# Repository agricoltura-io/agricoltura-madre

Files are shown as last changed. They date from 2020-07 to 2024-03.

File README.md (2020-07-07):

# agricoltura-madre
Wired and Wireless gateway for all Agricoltura sensors/module supports RS485, Sub1GHZ, and 2.4GHZ networks

Quick Specs:

Beaglebone Green Based Version - Cape
- Seeedstudio Beaglebone Green
- 2x RS485 ports
- Sub 1GHZ wirless modem with SMA Antenna Connector
- 2.4GHZ wireless modem with SMA Antenna connector, supporting all 2.4G types
- WiFi modem with SMA antenna connector
- 1x USB 2.0 ports
- USB serial monitor connection
- Ethernet

Beaglebone SiP Based Version
- OSD335x Family System-in-package, running Debian Linux
- 4x RS485 ports
- Sub 1GHZ wirless modem with SMA Antenna Connector
- 2.4GHZ wireless model with SMA Antenna connector, supporting all 2.4G types
- WiFi modem with SMA antenna connector
- 2X USB 2.0 ports
- USB serial monitor connection
- Ethernet

Raspberry Pi 4 based version:
- 2x RS485 ports
- Sub 1GHZ wirless modem with SMA Antenna Connector
- 2.4GHZ wireless model with SMA Antenna connector, supporting all 2.4G types
- Integrated WiFi (RPi4)
- USB ports (RPi4)
- Ethernet
- PoE or 24VAC Power

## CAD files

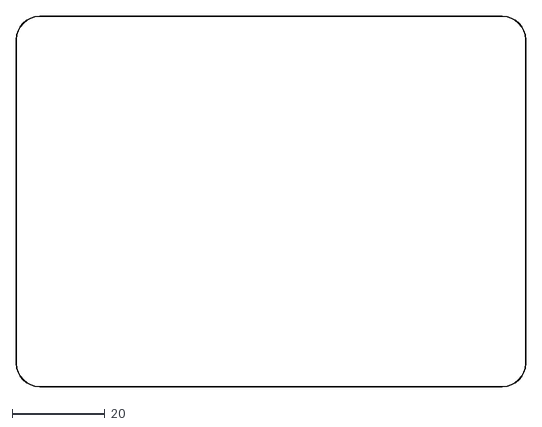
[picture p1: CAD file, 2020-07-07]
PCB/Cape/agricoltura-madre-cape-B/Vine_Ivy_BRD_Shape.dxf
110.0 x 80.0

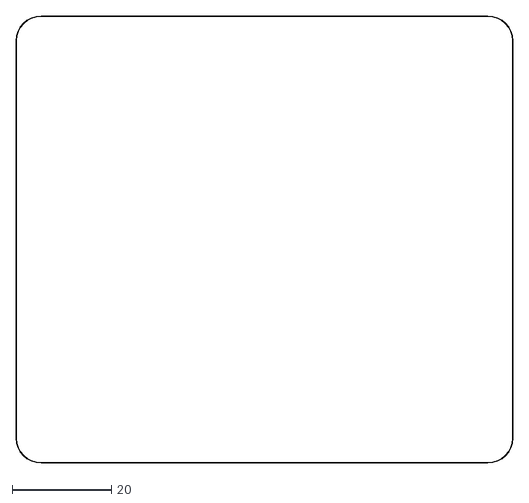
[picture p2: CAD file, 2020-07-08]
PCB/Cape/agricoltura-madre-cape/madre_BRD_Shape.dxf
100.0 x 90.0

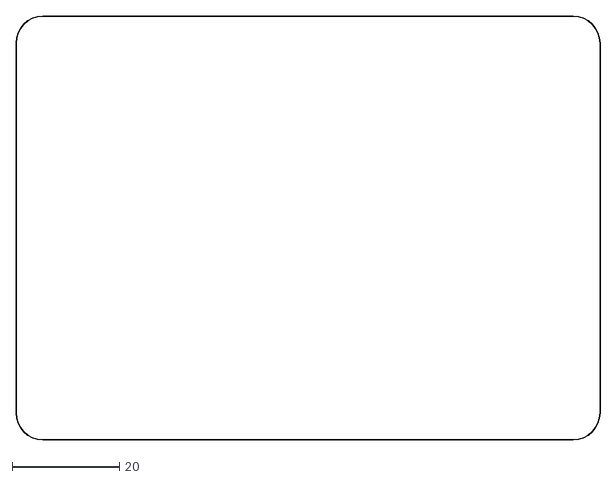
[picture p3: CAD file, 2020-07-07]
PCB/Cape/agricoltura-madre-cape-B/Vine_Ivy_BRD_Margin.dxf
109.0 x 79.0

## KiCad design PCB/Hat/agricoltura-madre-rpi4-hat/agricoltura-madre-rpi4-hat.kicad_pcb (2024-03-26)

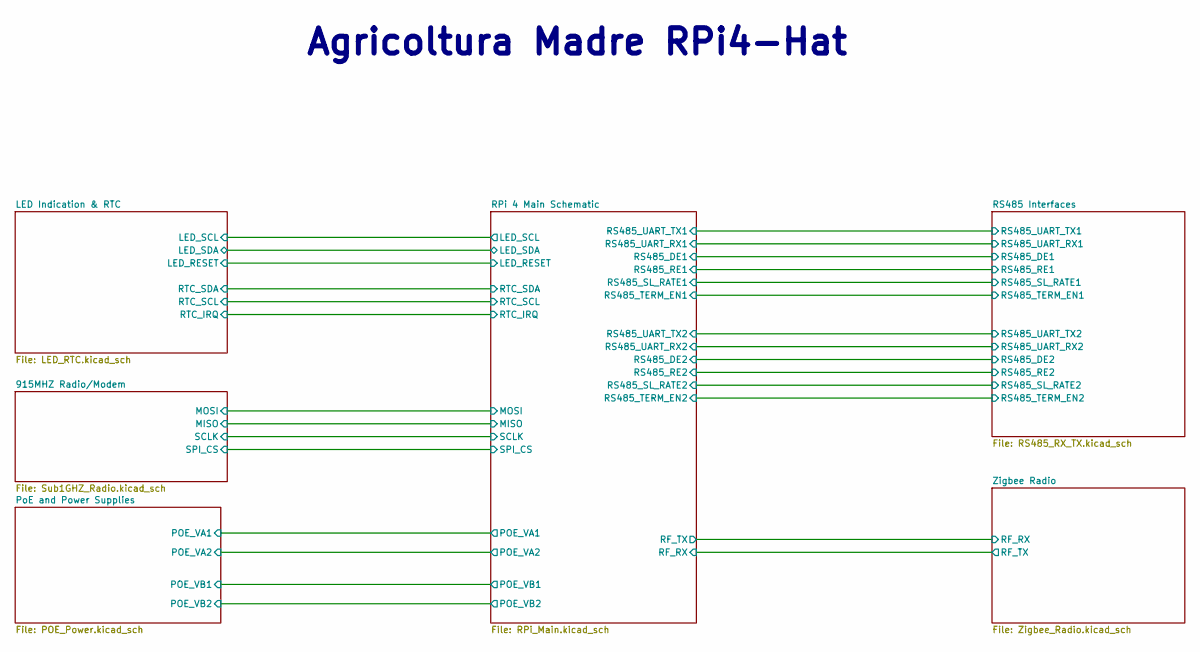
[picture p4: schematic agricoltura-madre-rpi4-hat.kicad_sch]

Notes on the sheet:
Agricoltura Madre RPi4-Hat

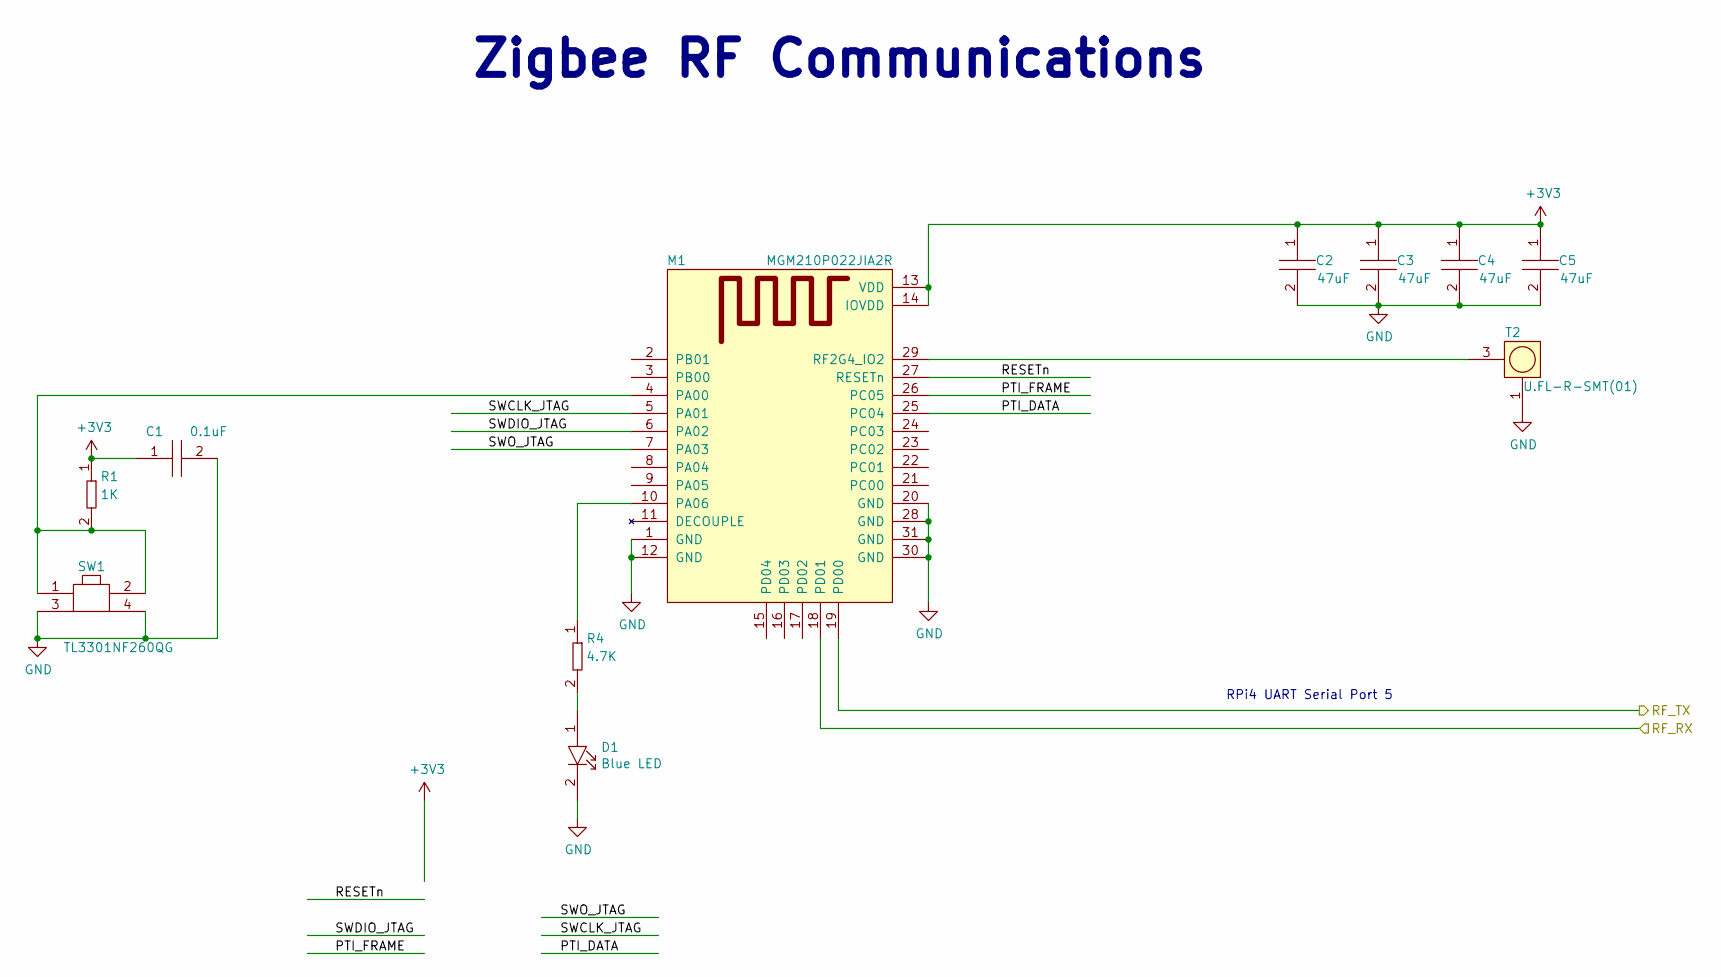
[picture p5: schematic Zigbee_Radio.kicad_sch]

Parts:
C1: GRM155R71E104KE14J; C0402; Tolerance 10%; Voltage 25V; MFR# GRM155R71E104KE14J
C2, C3, C4, C5: GRM188R60J476ME15D; C0603; Tolerance 20%; Voltage 6.3V; MFR# GRM188R60J476ME15D
D1: LTST-C194TBKT; LED0603; Tolerance *; Voltage 3.3V; MFR# LTST-C194TBKT
M1: MGM210P022JIA2R; Tolerance *; Voltage 1.8V-3.8V; MFR# MGM210P022JIA2R
R1: RC0402FR-071KL; R0402; Tolerance 1%; Voltage *; MFR# RC0402FR-071KL
R4: RC0402FR-074K7L; R0402; Tolerance 1%; Voltage *; MFR# RC0402FR-074K7L
SW1: TL3301NF260QG; Tolerance *; Voltage 12VDC; MFR# TL3301NF260QG
T2: U.FL-R-SMT(01); HRS_U.FL-R-SMT; Tolerance *; Voltage 3.3V; MFR# U.FL-R-SMT(01)

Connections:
+3V3: C1.1, C2.1, C3.1, C4.1, C5.1, M1.13 (VDD), M1.14 (IOVDD), R1.1; also elsewhere on the board
/RPi 4 Main Schematic/RF_RX: M1.19 (PD00); also elsewhere on the board
/Zigbee Radio /PTI_DATA: M1.25 (PC04)
/Zigbee Radio /PTI_FRAME: M1.26 (PC05)
/Zigbee Radio /RESETn: M1.27 (RESETn)
/Zigbee Radio /RF_RX: M1.18 (PD01); also elsewhere on the board
/Zigbee Radio /SWCLK_JTAG: M1.5 (PA01)
/Zigbee Radio /SWDIO_JTAG: M1.6 (PA02)
/Zigbee Radio /SWO_JTAG: M1.7 (PA03)
GND: C1.2, C2.2, C3.2, C4.2, C5.2, D1.2, M1.1 (GND), M1.12 (GND), M1.20 (GND), M1.28 (GND), M1.30 (GND), M1.31 (GND), SW1.3, SW1.4, T2.1; also elsewhere on the board
unnamed: D1.1, R4.2
unnamed: M1.4 (PA00), R1.2, SW1.1, SW1.2
unnamed: M1.10 (PA06), R4.1
unnamed: M1.29 (RF2G4_IO2), T2.3

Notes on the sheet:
Zigbee RF Communications
RPi4 UART Serial Port 5

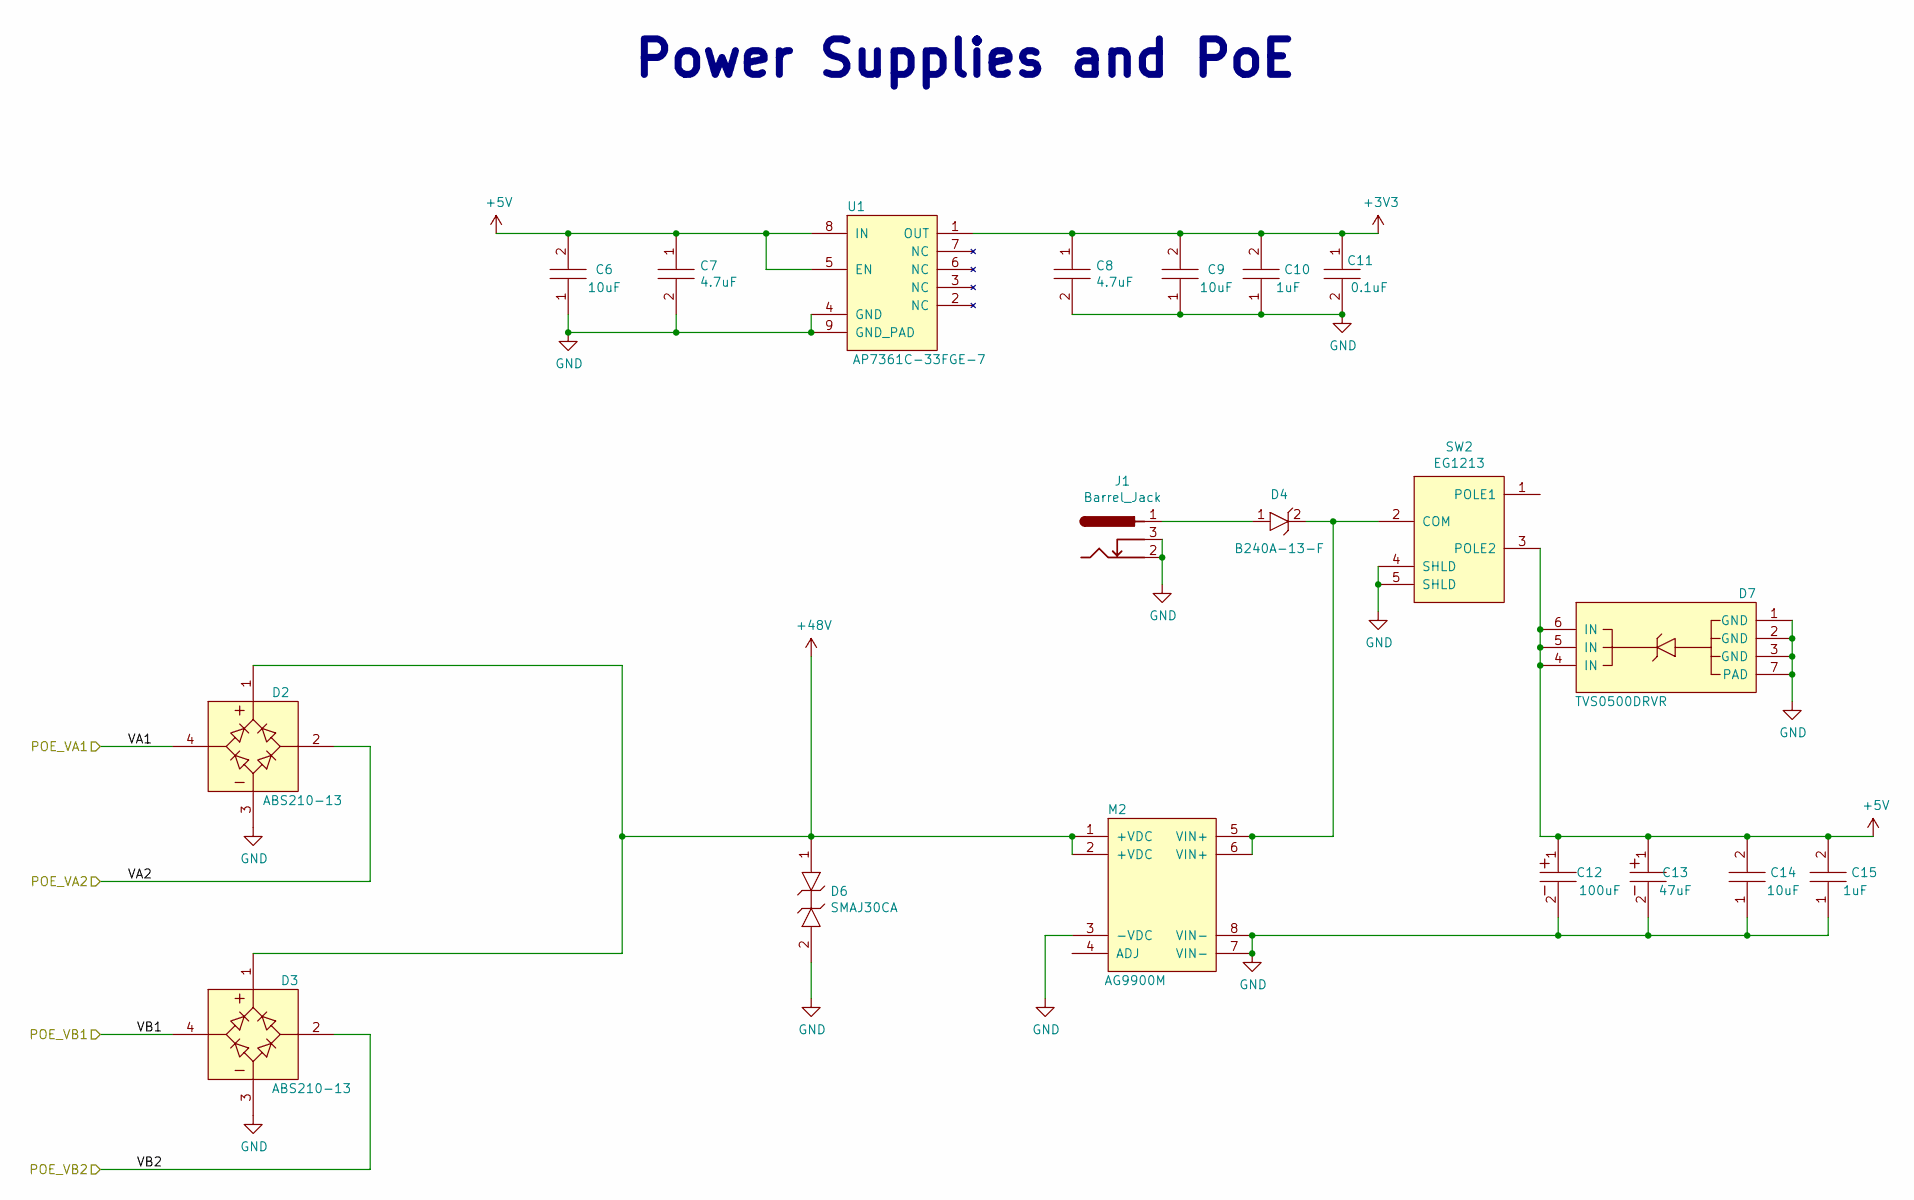
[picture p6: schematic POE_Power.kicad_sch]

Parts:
C6, C9, C14: GRM188R61A106KE69J; C0603; Tolerance 10%; Voltage 10V; MFR# GRM188R61A106KE69J
C7, C8: GRM155R61A475MEAAD; C0402; Tolerance 20%; Voltage 10V; MFR# GRM155R61A475MEAAD
C10, C15: GRM155C81A105KA12D; C0402; Tolerance 10%; Voltage 10V; MFR# GRM155C81A105KA12D
C11: GRM155R71E104KE14J; C0402; Tolerance 10%; Voltage 25V; MFR# GRM155R71E104KE14J
C12: UUX1J101MNL1GS; Tolerance 20%; Voltage 63V; MFR# UUX1J101MNL1GS
C13: UWT1H470MCL1GS; Tolerance 20%; Voltage 63V; MFR# UWT1H470MCL1GS
D2, D3: ABS210-13; Tolerance *; Voltage 1KV 2A; MFR# ABS210-13
D4: B240A-13-F; Tolerance *; Voltage 40V; MFR# B240A-13-F
D6: SMAJ30CA; Tolerance *; Voltage 48.4V; MFR# SMAJ30CA
D7: TVS0500DRVR; Tolerance *; Voltage 5V; MFR# TVS0500DRVR
J1: Barrel_Jack; BARREL_JACK
M2: AG9900M; 9900M_POE; Tolerance *; Voltage *; MFR# *
SW2: EG1213; SW_EG1213; Tolerance *; Voltage 30V; MFR# EG1213
U1: AP7361C-33FGE-7; DFN3030-8; Tolerance *; Voltage 6VIN MAX 3.3V out; MFR# AP7361C-33FGE-7

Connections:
+3V3: C8.1, C9.2, C10.2, C11.1, U1.1 (OUT); also elsewhere on the board
+5V: C6.2, C7.1, C12.1, C13.1, C14.2, C15.2, D7.4 (IN), D7.5 (IN), D7.6 (IN), SW2.3 (POLE2), U1.5 (EN), U1.8 (IN); also elsewhere on the board
+48V: D2.1, D3.1, D6.1, M2.1 (+VDC), M2.2 (+VDC)
/PoE and Power Supplies/POE_VA1: D2.4; also elsewhere on the board
/PoE and Power Supplies/POE_VA2: D2.2; also elsewhere on the board
/PoE and Power Supplies/POE_VB1: D3.4; also elsewhere on the board
/PoE and Power Supplies/POE_VB2: D3.2; also elsewhere on the board
GND: C6.1, C7.2, C8.2, C9.1, C10.1, C11.2, C12.2, C13.2, C14.1, C15.1, D2.3, D3.3, D6.2, D7.1 (GND), D7.2 (GND), D7.3 (GND), D7.7 (PAD), J1.2, J1.3, M2.3 (-VDC), M2.7 (VIN-), M2.8 (VIN-), SW2.4 (SHLD), SW2.5 (SHLD), U1.4 (GND), U1.9 (GND_PAD); also elsewhere on the board
unnamed: D4.1, J1.1
unnamed: D4.2, M2.5 (VIN+), M2.6 (VIN+), SW2.2 (COM)

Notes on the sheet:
Power Supplies and PoE

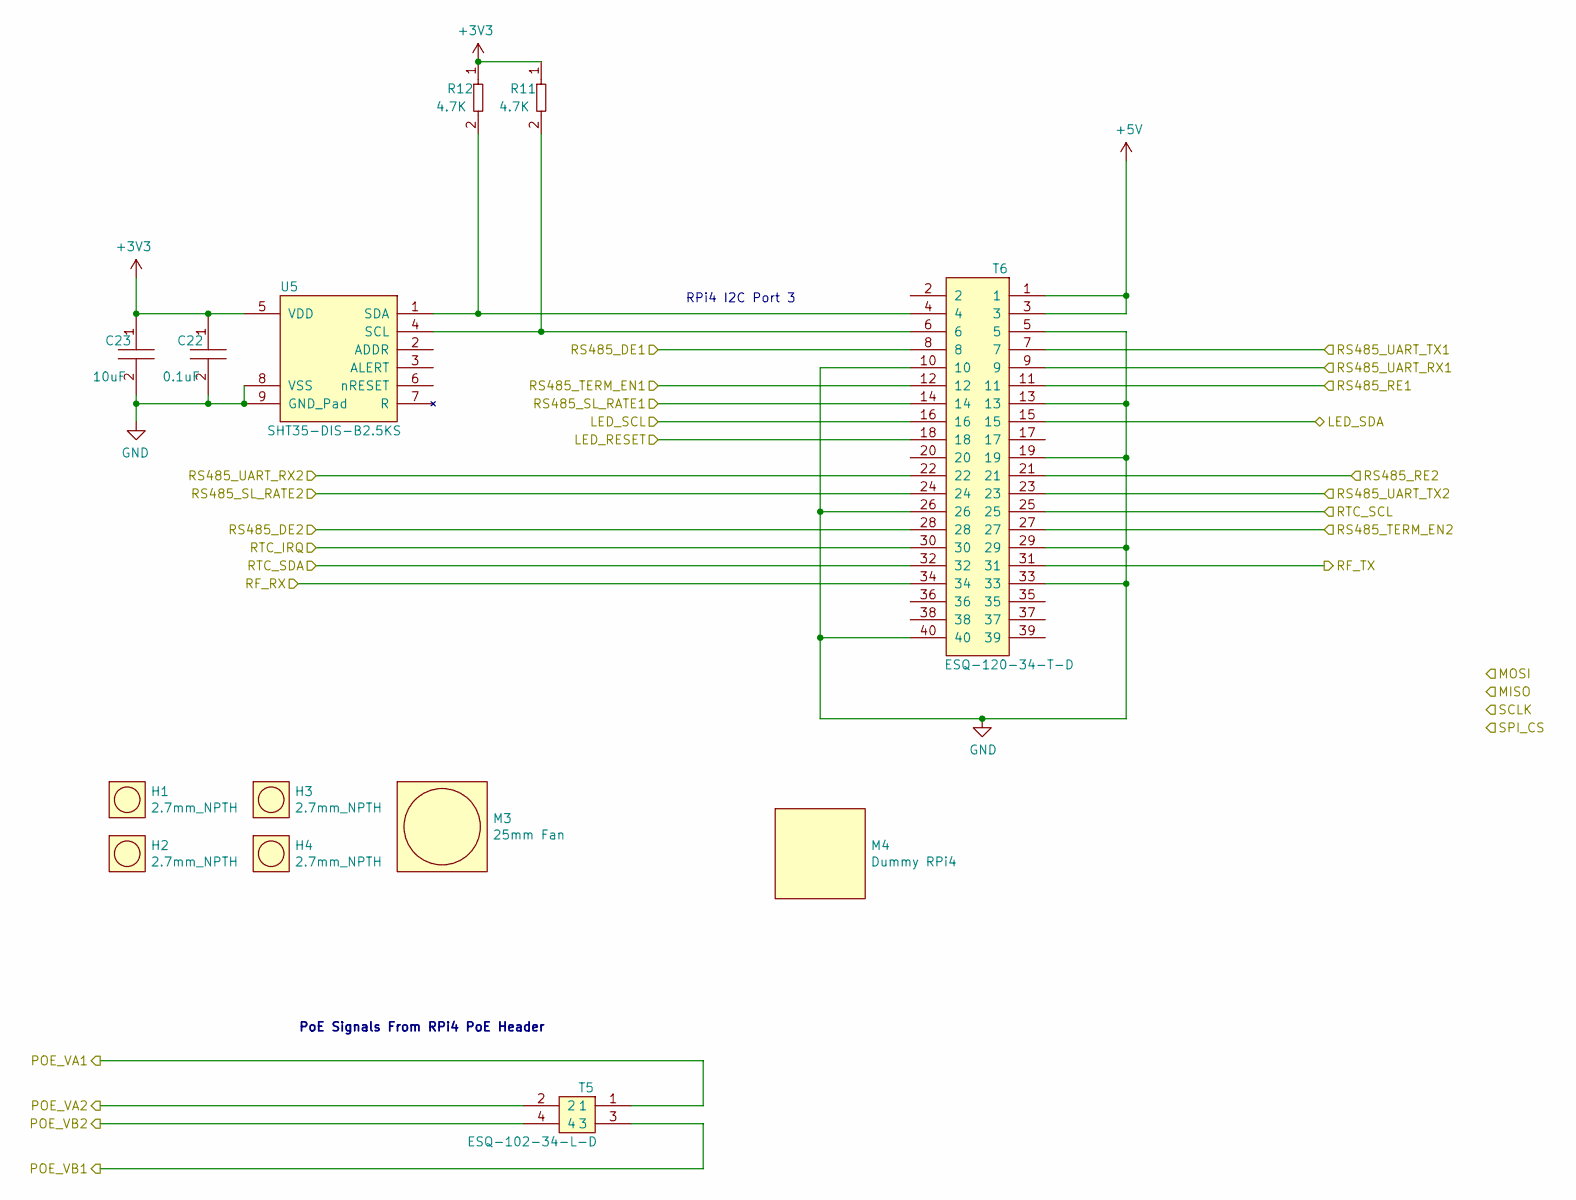
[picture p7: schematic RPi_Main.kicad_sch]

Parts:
C22: GRM155R71E104KE14J; C0402; Tolerance 10%; Voltage 25V; MFR# GRM155R71E104KE14J
C23: GRM188R61A106KE69J; C0603; Tolerance 10%; Voltage 10V; MFR# GRM188R61A106KE69J
H1, H2, H3, H4: 2.7mm_NPTH; Tolerance *; Voltage *; MFR# *
M3: 25mm_FAN; Tolerance *; Voltage *; MFR# *
M4: DummyPi; RPi4_SHAPE_3D; Tolerance *; Voltage *; MFR# *
R11, R12: RC0402FR-074K7L; R0402; Tolerance 1%; Voltage *; MFR# RC0402FR-074K7L
T5: ESQ-102-34-L-D; Tolerance *; Voltage 550VAC; MFR# ESQ-102-34-L-D
T6: ESQ-120-34-T-D; ESQ-120-34-T-D_2x20_Pitch2.54mm; Tolerance *; Voltage 550VAC; MFR# ESQ-120-34-T-D
U5: SHT35-DIS-B2.5KS; DFN8_SHT35; Tolerance *; Voltage 2.15V-5.5V; MFR# SHT35-DIS-B2.5KS

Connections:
+3V3: C22.1, C23.1, R11.1, R12.1, U5.5 (VDD); also elsewhere on the board
+5V: T6.1, T6.3; also elsewhere on the board
/LED Indication & RTC/LED_RESET: T6.18; also elsewhere on the board
/LED Indication & RTC/LED_SCL: T6.16; also elsewhere on the board
/LED Indication & RTC/LED_SDA: T6.15; also elsewhere on the board
/LED Indication & RTC/RTC_IRQ: T6.30; also elsewhere on the board
/LED Indication & RTC/RTC_SCL: T6.25; also elsewhere on the board
/LED Indication & RTC/RTC_SDA: T6.32; also elsewhere on the board
/PoE and Power Supplies/POE_VA1: T5.1; also elsewhere on the board
/PoE and Power Supplies/POE_VA2: T5.2; also elsewhere on the board
/PoE and Power Supplies/POE_VB1: T5.3; also elsewhere on the board
/PoE and Power Supplies/POE_VB2: T5.4; also elsewhere on the board
/RPi 4 Main Schematic/RF_RX: T6.34; also elsewhere on the board
/RPi 4 Main Schematic/RS485_DE1: T6.8; also elsewhere on the board
/RPi 4 Main Schematic/RS485_DE2: T6.28; also elsewhere on the board
/RPi 4 Main Schematic/RS485_RE1: T6.11; also elsewhere on the board
/RPi 4 Main Schematic/RS485_RE2: T6.21; also elsewhere on the board
/RPi 4 Main Schematic/RS485_SL_RATE1: T6.14; also elsewhere on the board
/RPi 4 Main Schematic/RS485_SL_RATE2: T6.24; also elsewhere on the board
/RPi 4 Main Schematic/RS485_TERM_EN1: T6.12; also elsewhere on the board
/RPi 4 Main Schematic/RS485_TERM_EN2: T6.27; also elsewhere on the board
/RPi 4 Main Schematic/RS485_UART_RX1: T6.9; also elsewhere on the board
/RPi 4 Main Schematic/RS485_UART_RX2: T6.22; also elsewhere on the board
/RPi 4 Main Schematic/RS485_UART_TX1: T6.7; also elsewhere on the board
/RPi 4 Main Schematic/RS485_UART_TX2: T6.23; also elsewhere on the board
/Zigbee Radio /RF_RX: T6.31; also elsewhere on the board
GND: C22.2, C23.2, T6.5, T6.10, T6.13, T6.19, T6.26, T6.29, T6.33, T6.40, U5.8 (VSS), U5.9 (GND_Pad); also elsewhere on the board
unnamed: R11.2, T6.6, U5.4 (SCL)
unnamed: R12.2, T6.4, U5.1 (SDA)

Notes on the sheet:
PoE Signals From RPi4 PoE Header
RPi4 I2C Port 3

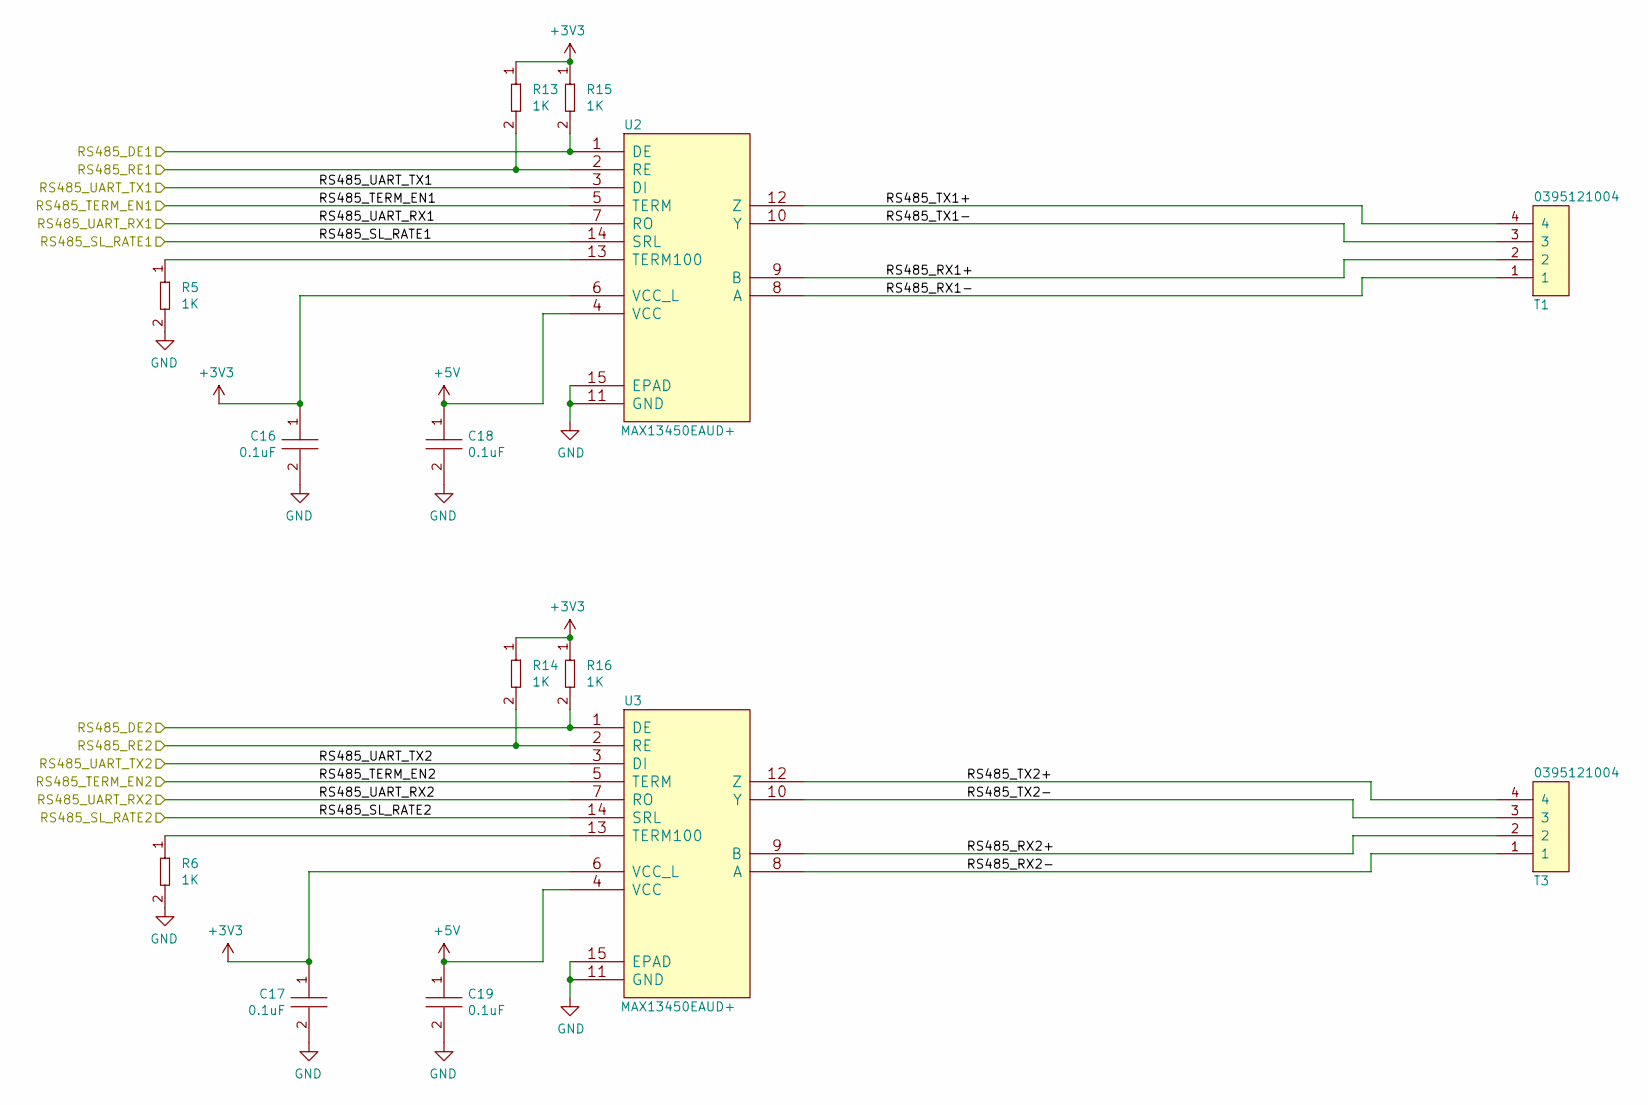
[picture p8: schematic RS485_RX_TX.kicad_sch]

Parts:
C16, C17: C0402C104K9PACTU; R0402; Tolerance 10%; Voltage 6.3V; MFR# C0402C104K9PACTU
C18, C19: CGA3E2X7R1H104K080AA; C0603; Tolerance 10%; Voltage 50V; MFR# CGA3E2X7R1H104K080AA
R5, R6, R13, R14, R15, R16: RC0402FR-071KL; R0402; Tolerance 1%; Voltage *; MFR# RC0402FR-071KL
T1, T3: 0395121004; Tolerance *; Voltage 300V; MFR# 0395121004
U2, U3: MAX13450EAUD+; MAX13450EAUD&plus_; Tolerance *; Voltage 4.75V ~ 5.25V; MFR# MAX13450EAUD+

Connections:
+3V3: C16.1, C17.1, R13.1, R14.1, R15.1, R16.1, U2.6 (VCC_L), U3.6 (VCC_L); also elsewhere on the board
+5V: C18.1, C19.1, U2.4 (VCC), U3.4 (VCC); also elsewhere on the board
/RPi 4 Main Schematic/RS485_DE1: R15.2, U2.1 (DE); also elsewhere on the board
/RPi 4 Main Schematic/RS485_DE2: R16.2, U3.1 (DE); also elsewhere on the board
/RPi 4 Main Schematic/RS485_RE1: R13.2, U2.2 (RE); also elsewhere on the board
/RPi 4 Main Schematic/RS485_RE2: R14.2, U3.2 (RE); also elsewhere on the board
/RPi 4 Main Schematic/RS485_SL_RATE1: U2.14 (SRL); also elsewhere on the board
/RPi 4 Main Schematic/RS485_SL_RATE2: U3.14 (SRL); also elsewhere on the board
/RPi 4 Main Schematic/RS485_TERM_EN1: U2.5 (TERM); also elsewhere on the board
/RPi 4 Main Schematic/RS485_TERM_EN2: U3.5 (TERM); also elsewhere on the board
/RPi 4 Main Schematic/RS485_UART_RX1: U2.7 (RO); also elsewhere on the board
/RPi 4 Main Schematic/RS485_UART_RX2: U3.7 (RO); also elsewhere on the board
/RPi 4 Main Schematic/RS485_UART_TX1: U2.3 (DI); also elsewhere on the board
/RPi 4 Main Schematic/RS485_UART_TX2: U3.3 (DI); also elsewhere on the board
/RS485 Interfaces/RS485_RX1+: T1.2, U2.9 (B)
/RS485 Interfaces/RS485_RX1-: T1.1, U2.8 (A)
/RS485 Interfaces/RS485_RX2+: T3.2, U3.9 (B)
/RS485 Interfaces/RS485_RX2-: T3.1, U3.8 (A)
/RS485 Interfaces/RS485_TX1+: T1.4, U2.12 (Z)
/RS485 Interfaces/RS485_TX1-: T1.3, U2.10 (Y)
/RS485 Interfaces/RS485_TX2+: T3.4, U3.12 (Z)
/RS485 Interfaces/RS485_TX2-: T3.3, U3.10 (Y)
GND: C16.2, C17.2, C18.2, C19.2, R5.2, R6.2, U2.11 (GND), U2.15 (EPAD), U3.11 (GND), U3.15 (EPAD); also elsewhere on the board
unnamed: R5.1, U2.13 (TERM100)
unnamed: R6.1, U3.13 (TERM100)

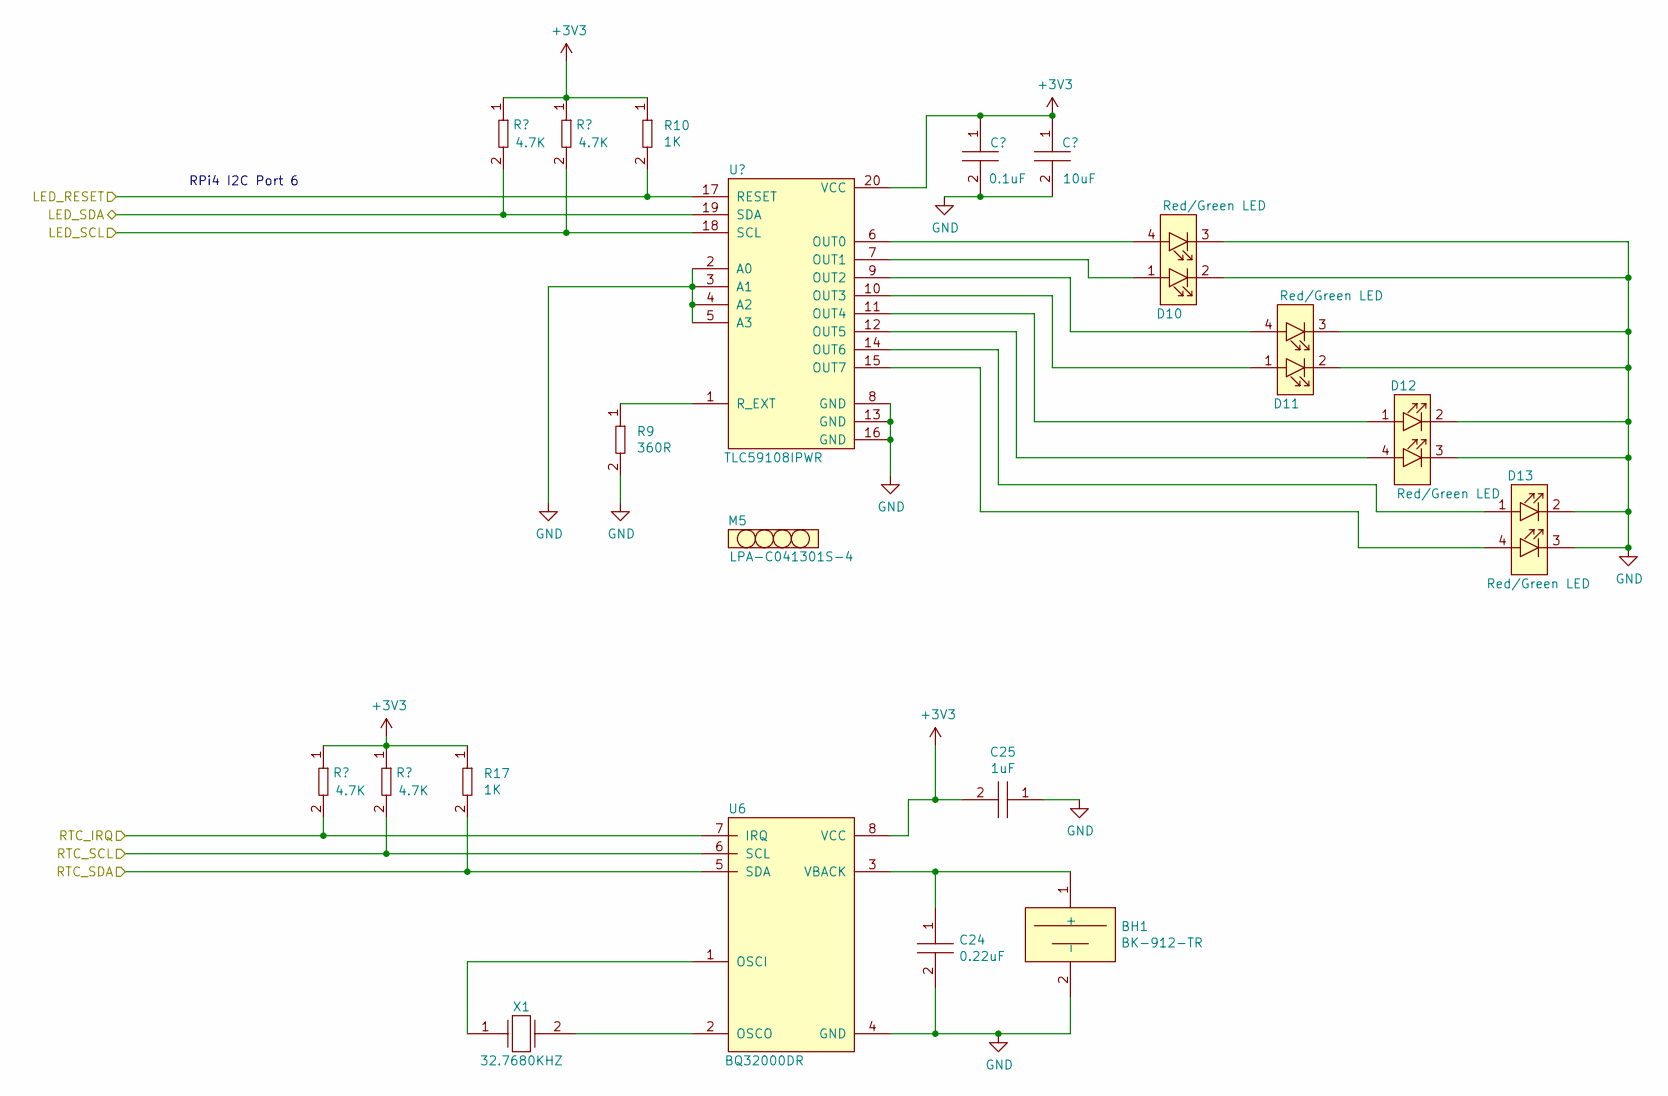
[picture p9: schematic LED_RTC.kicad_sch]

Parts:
BH1: BK-912-TR; BK-912; Tolerance *; Voltage 3V; MFR# BK-912-TR
C20: GRM155R71E104KE14J; C0402; Tolerance 10%; Voltage 25V; MFR# GRM155R71E104KE14J
C21: GRM188R61A106KE69J; C0603; Tolerance 10%; Voltage 10V; MFR# GRM188R61A106KE69J
C24: GRM155R71A224KE01D; C0402; Tolerance 10%; Voltage 10V; MFR# GRM155R71A224KE01D
C25: GRM155C81A105KA12D; C0402; Tolerance 10%; Voltage 10V; MFR# GRM155C81A105KA12D
D10, D11, D12, D13: APHBM2012SURKCGKC; LED_APHBM2012SURKCGKC; Tolerance *; Voltage 2.1V/1.95V; MFR# APHBM2012SURKCGKC
M5: LPA-C041301S-4; Tolerance *; Voltage *; MFR# LPA-C041301S-4
R2, R3, R7, R8: RC0402FR-074K7L; R0402; Tolerance 1%; Voltage *; MFR# RC0402FR-074K7L
R9: RC0402FR-07360RL; R0402; Tolerance 1%; Voltage *; MFR# RC0402FR-07360RL
R10, R17: RC0402FR-071KL; R0402; Tolerance 1%; Voltage *; MFR# RC0402FR-071KL
U4: TLC59108IPWR; 20TSSOP_Ti_PWR; Tolerance *; Voltage 3-5.5V IN, 17V OUT; MFR# Texas Instruments
U6: BQ32000DR; Tolerance *; Voltage 3.3V; MFR# IC RTC CLK/CALENDAR I2C 8-SOIC
X1: ECS-.327-12.5-34B-TR; Tolerance *; Voltage *; MFR# ECS-.327-12.5-34B-TR

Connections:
+3V3: C20.1, C21.1, C25.2, R2.1, R3.1, R7.1, R8.1, R10.1, R17.1, U4.20 (VCC), U6.8 (VCC); also elsewhere on the board
/LED Indication & RTC/LED_RESET: R10.2, U4.17 (RESET); also elsewhere on the board
/LED Indication & RTC/LED_SCL: R8.2, U4.18 (SCL); also elsewhere on the board
/LED Indication & RTC/LED_SDA: R7.2, U4.19 (SDA); also elsewhere on the board
/LED Indication & RTC/RTC_IRQ: R2.2, U6.7 (IRQ); also elsewhere on the board
/LED Indication & RTC/RTC_SCL: R3.2, U6.6 (SCL); also elsewhere on the board
/LED Indication & RTC/RTC_SDA: R17.2, U6.5 (SDA); also elsewhere on the board
GND: BH1.2 (-), C20.2, C21.2, C24.2, C25.1, D10.2, D10.3, D11.2, D11.3, D12.2, D12.3, D13.2, D13.3, R9.2, U4.2 (A0), U4.3 (A1), U4.4 (A2), U4.5 (A3), U4.8 (GND), U4.13 (GND), U4.16 (GND), U6.4 (GND); also elsewhere on the board
unnamed: BH1.1 (+), C24.1, U6.3 (VBACK)
unnamed: D10.1, U4.7 (OUT1)
unnamed: D10.4, U4.6 (OUT0)
unnamed: D11.1, U4.10 (OUT3)
unnamed: D11.4, U4.9 (OUT2)
unnamed: D12.1, U4.11 (OUT4)
unnamed: D12.4, U4.12 (OUT5)
unnamed: D13.1, U4.14 (OUT6)
unnamed: D13.4, U4.15 (OUT7)
unnamed: R9.1, U4.1 (R_EXT)
unnamed: U6.1 (OSCI), X1.1
unnamed: U6.2 (OSCO), X1.2

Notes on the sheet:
RPi4 I2C Port 6

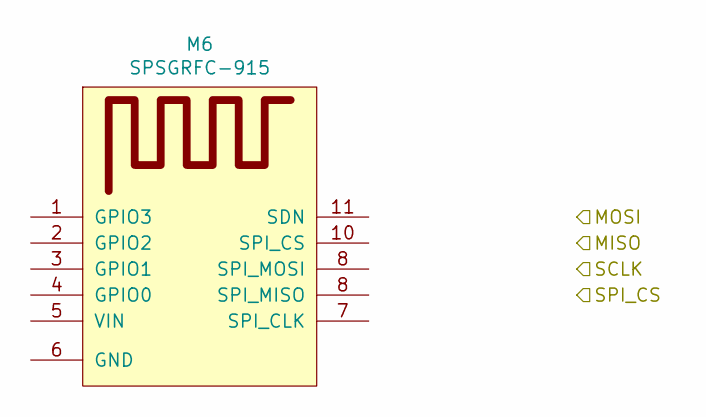
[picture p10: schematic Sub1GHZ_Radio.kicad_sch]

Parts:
M6: SPSGRFC-915; XCVR_SPSGRF-915; Tolerance *; Voltage 1.8V ~ 3.6V; MFR# SPSGRFC-915

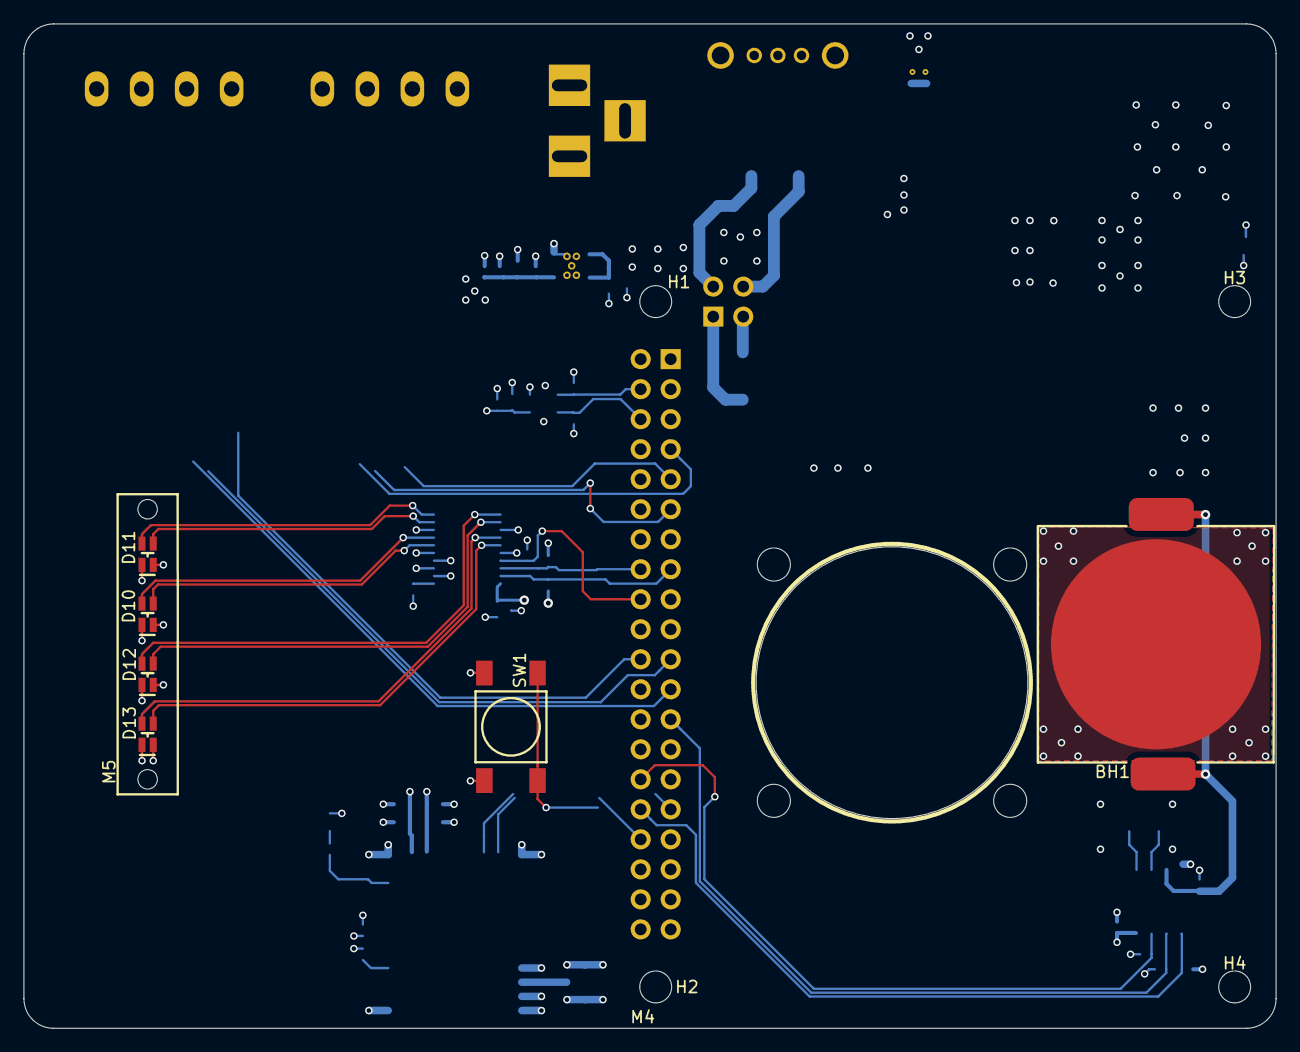
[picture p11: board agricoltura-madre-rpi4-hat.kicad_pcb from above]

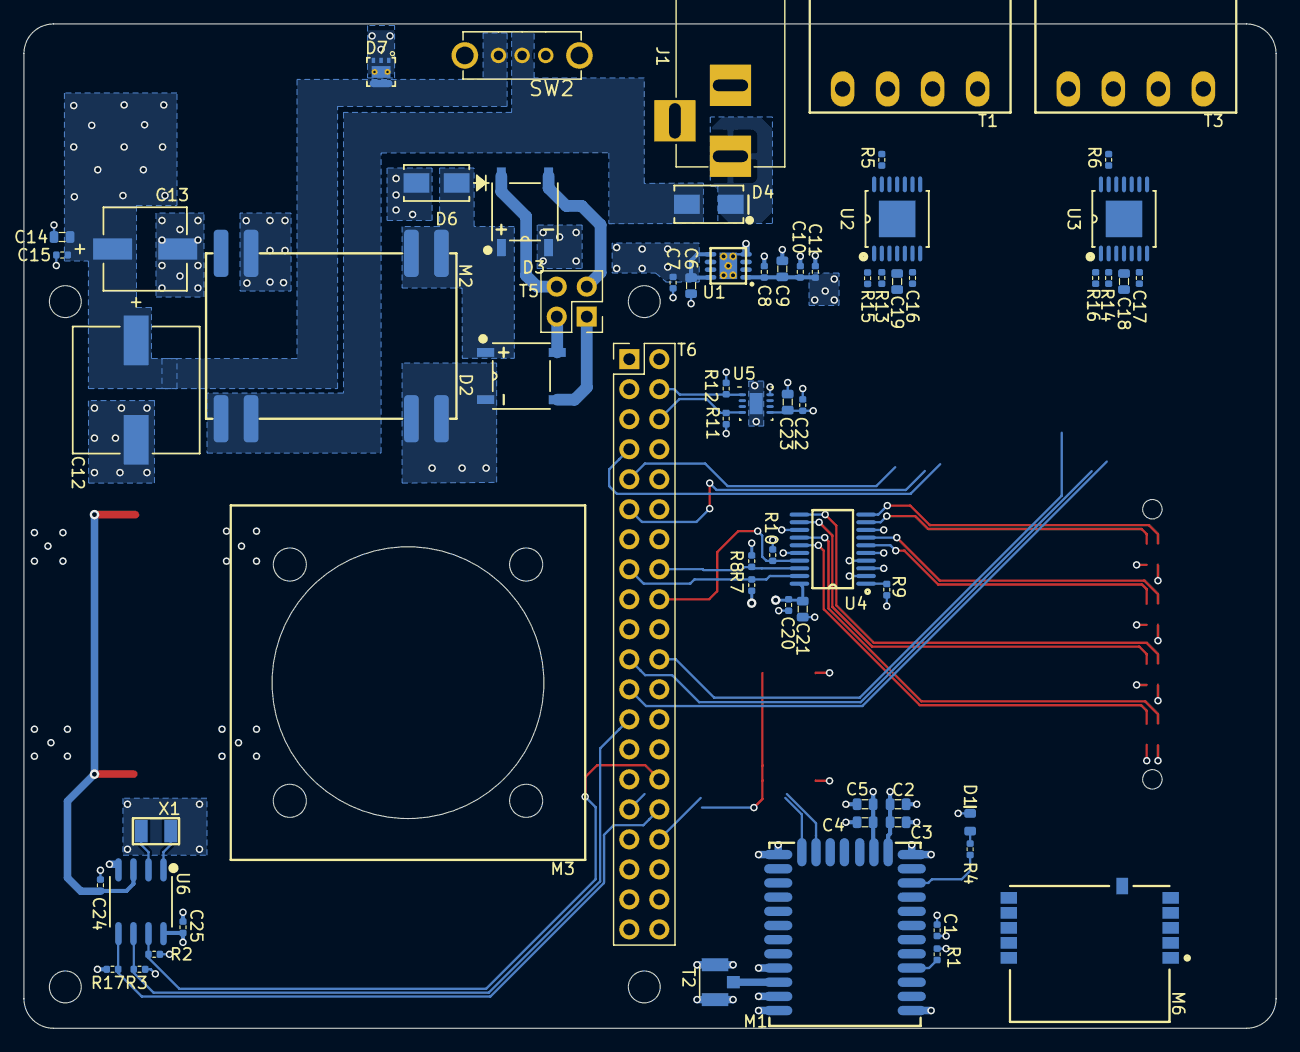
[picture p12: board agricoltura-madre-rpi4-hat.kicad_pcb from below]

Board: 4 copper layers, 106.0 x 85.0 mm, 78 parts (66 on the bottom side), 58 nets.

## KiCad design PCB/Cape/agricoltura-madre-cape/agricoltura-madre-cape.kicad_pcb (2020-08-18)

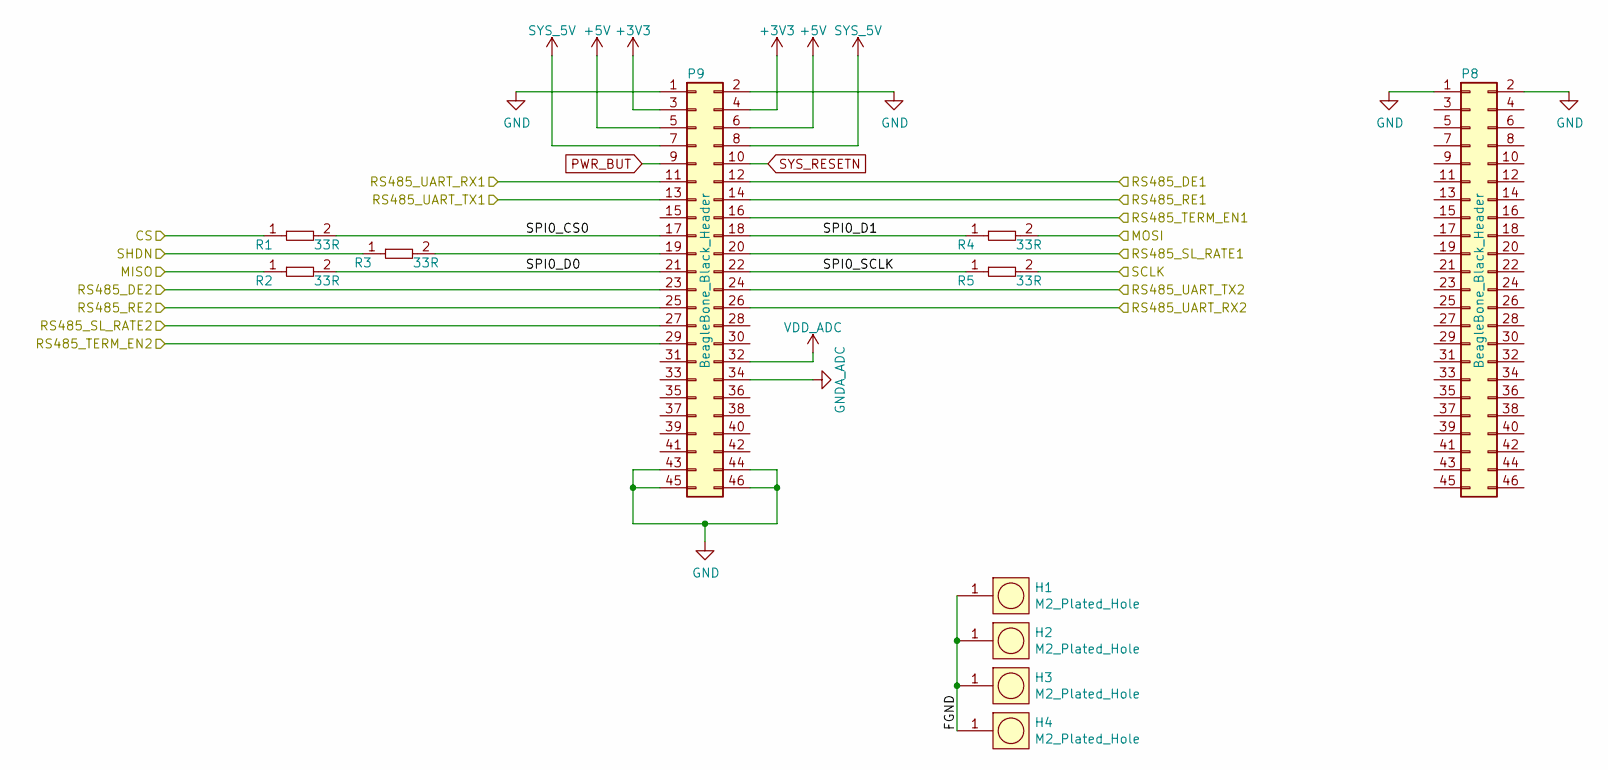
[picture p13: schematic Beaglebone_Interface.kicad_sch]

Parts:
H1, H2, H3, H4: M2_Plated_Hole; M2_HOLE; Tolerance *; Voltage *; MFR# *
P8, P9: BeagleBone_Black_Header; Socket_BeagleBone_Black
R1, R2, R3, R4, R5: RC0402FR-0733RL; R0402; Tolerance 1%; Voltage *; MFR# RC0402FR-0733RL

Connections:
+3V3: P9.3, P9.4; also elsewhere on the board
+5V: P9.5, P9.6; also elsewhere on the board
/915MHZ Radio/Modem/CS: R1.1; also elsewhere on the board
/915MHZ Radio/Modem/MISO: R2.1; also elsewhere on the board
/915MHZ Radio/Modem/MOSI: R4.2
/915MHZ Radio/Modem/SCLK: R5.2; also elsewhere on the board
/915MHZ Radio/Modem/SHDN: R3.1; also elsewhere on the board
/Beaglebone Interface/FGND: H1.1, H2.1, H3.1, H4.1
/Beaglebone Interface/RS485_DE1: P9.12; also elsewhere on the board
/Beaglebone Interface/RS485_DE2: P9.23; also elsewhere on the board
/Beaglebone Interface/RS485_RE1: P9.14; also elsewhere on the board
/Beaglebone Interface/RS485_RE2: P9.25; also elsewhere on the board
/Beaglebone Interface/RS485_SL_RATE1: P9.20; also elsewhere on the board
/Beaglebone Interface/RS485_SL_RATE2: P9.27; also elsewhere on the board
/Beaglebone Interface/RS485_TERM_EN1: P9.16; also elsewhere on the board
/Beaglebone Interface/RS485_TERM_EN2: P9.29; also elsewhere on the board
/Beaglebone Interface/RS485_UART_RX1: P9.11; also elsewhere on the board
/Beaglebone Interface/RS485_UART_RX2: P9.26; also elsewhere on the board
/Beaglebone Interface/RS485_UART_TX1: P9.13; also elsewhere on the board
/Beaglebone Interface/RS485_UART_TX2: P9.24; also elsewhere on the board
/Beaglebone Interface/SPI0_CS0: P9.17, R1.2
/Beaglebone Interface/SPI0_D0: P9.21, R2.2
/Beaglebone Interface/SPI0_D1: P9.18, R4.1
/Beaglebone Interface/SPI0_SCLK: P9.22, R5.1
GND: P8.1, P8.2, P9.1, P9.2, P9.43, P9.44, P9.45, P9.46; also elsewhere on the board
GNDA_ADC: P9.34
unnamed: P9.19, R3.2
PWR_BUT: P9.9
SYS_5V: P9.7, P9.8
SYS_RESETN: P9.10
VDD_ADC: P9.32

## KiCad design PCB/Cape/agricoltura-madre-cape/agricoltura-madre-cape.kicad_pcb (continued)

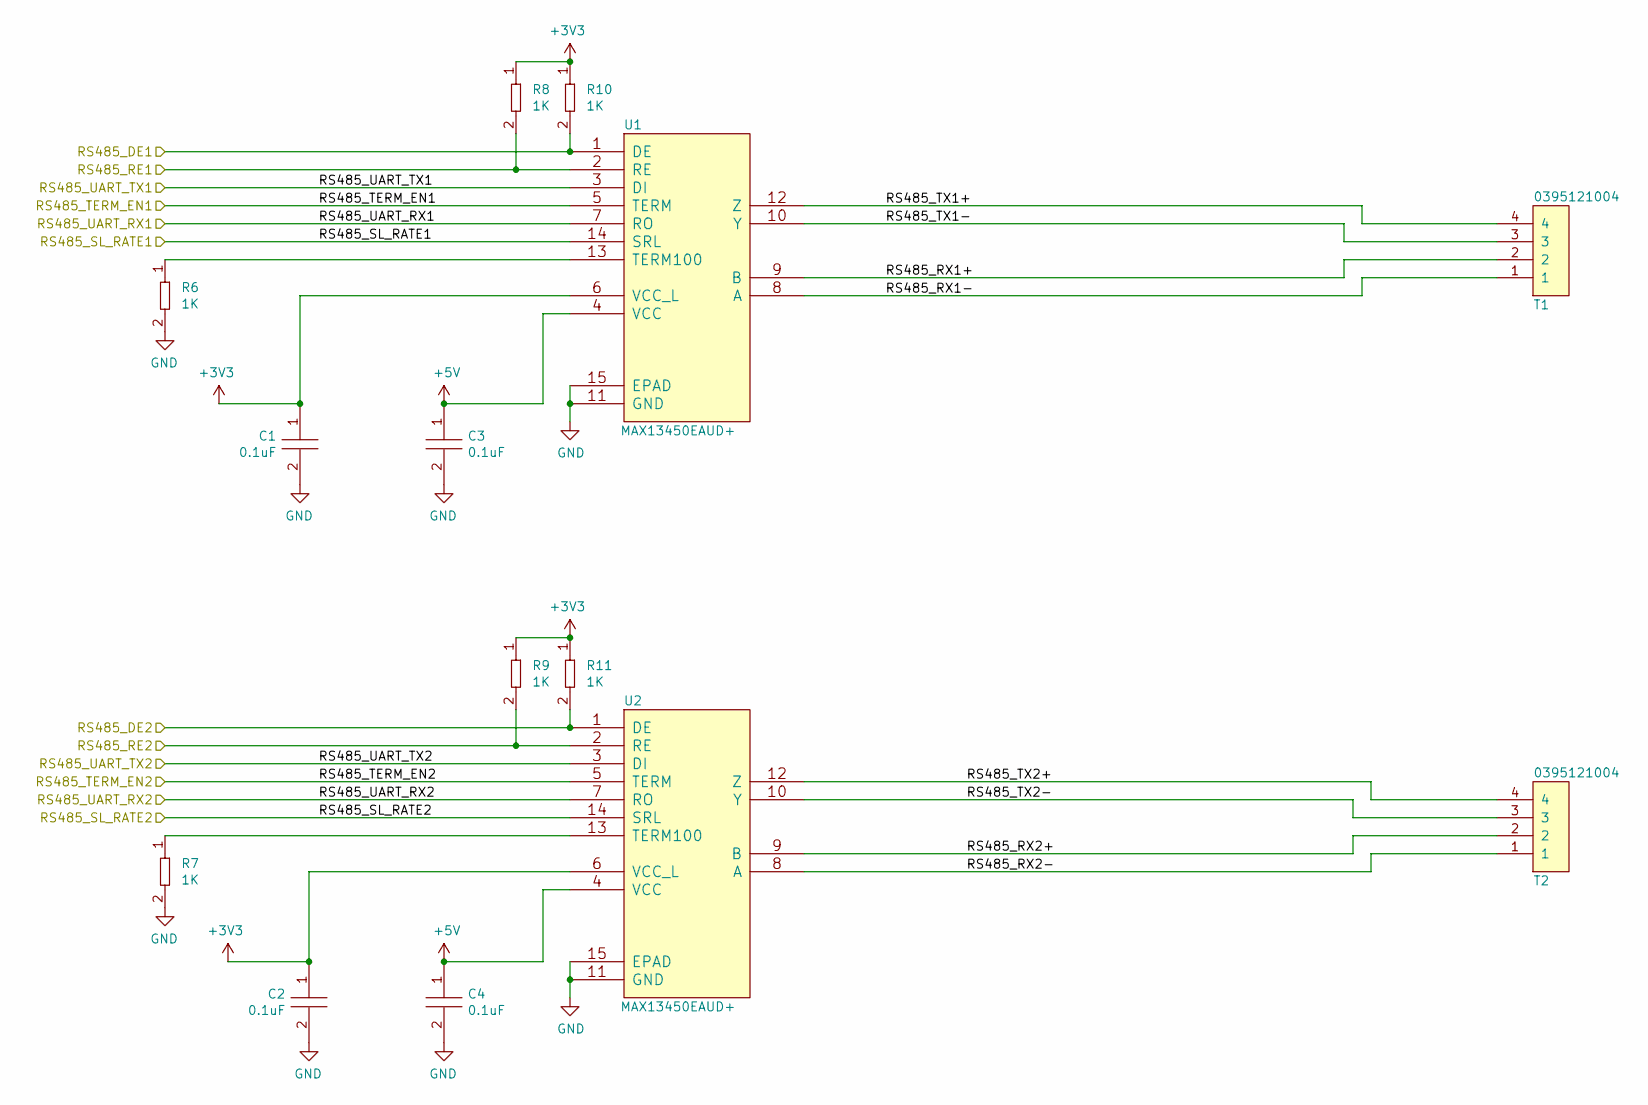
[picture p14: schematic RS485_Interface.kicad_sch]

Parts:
C1, C2: C0402C104K9PACTU; R0402; Tolerance 10%; Voltage 6.3V; MFR# C0402C104K9PACTU
C3, C4: CGA3E2X7R1H104K080AA; C0603; Tolerance 10%; Voltage 50V; MFR# CGA3E2X7R1H104K080AA
R6, R7, R8, R9, R10, R11: RC0402FR-071KL; R0402; Tolerance 1%; Voltage *; MFR# RC0402FR-071KL
T1, T2: 0395121004; Tolerance *; Voltage 300V; MFR# 0395121004
U1, U2: MAX13450EAUD+; MAX13450EAUD&plus_; Tolerance *; Voltage 4.75V ~ 5.25V; MFR# MAX13450EAUD+

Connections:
+3V3: C1.1, C2.1, R8.1, R9.1, R10.1, R11.1, U1.6 (VCC_L), U2.6 (VCC_L); also elsewhere on the board
+5V: C3.1, C4.1, U1.4 (VCC), U2.4 (VCC); also elsewhere on the board
/Beaglebone Interface/RS485_DE1: R10.2, U1.1 (DE); also elsewhere on the board
/Beaglebone Interface/RS485_DE2: R11.2, U2.1 (DE); also elsewhere on the board
/Beaglebone Interface/RS485_RE1: R8.2, U1.2 (RE); also elsewhere on the board
/Beaglebone Interface/RS485_RE2: R9.2, U2.2 (RE); also elsewhere on the board
/Beaglebone Interface/RS485_SL_RATE1: U1.14 (SRL); also elsewhere on the board
/Beaglebone Interface/RS485_SL_RATE2: U2.14 (SRL); also elsewhere on the board
/Beaglebone Interface/RS485_TERM_EN1: U1.5 (TERM); also elsewhere on the board
/Beaglebone Interface/RS485_TERM_EN2: U2.5 (TERM); also elsewhere on the board
/Beaglebone Interface/RS485_UART_RX1: U1.7 (RO); also elsewhere on the board
/Beaglebone Interface/RS485_UART_RX2: U2.7 (RO); also elsewhere on the board
/Beaglebone Interface/RS485_UART_TX1: U1.3 (DI); also elsewhere on the board
/Beaglebone Interface/RS485_UART_TX2: U2.3 (DI); also elsewhere on the board
/RS485 Interface/RS485_RX1+: T1.2, U1.9 (B)
/RS485 Interface/RS485_RX1-: T1.1, U1.8 (A)
/RS485 Interface/RS485_RX2+: T2.2, U2.9 (B)
/RS485 Interface/RS485_RX2-: T2.1, U2.8 (A)
/RS485 Interface/RS485_TX1+: T1.4, U1.12 (Z)
/RS485 Interface/RS485_TX1-: T1.3, U1.10 (Y)
/RS485 Interface/RS485_TX2+: T2.4, U2.12 (Z)
/RS485 Interface/RS485_TX2-: T2.3, U2.10 (Y)
GND: C1.2, C2.2, C3.2, C4.2, R6.2, R7.2, U1.11 (GND), U1.15 (EPAD), U2.11 (GND), U2.15 (EPAD); also elsewhere on the board
unnamed: R6.1, U1.13 (TERM100)
unnamed: R7.1, U2.13 (TERM100)

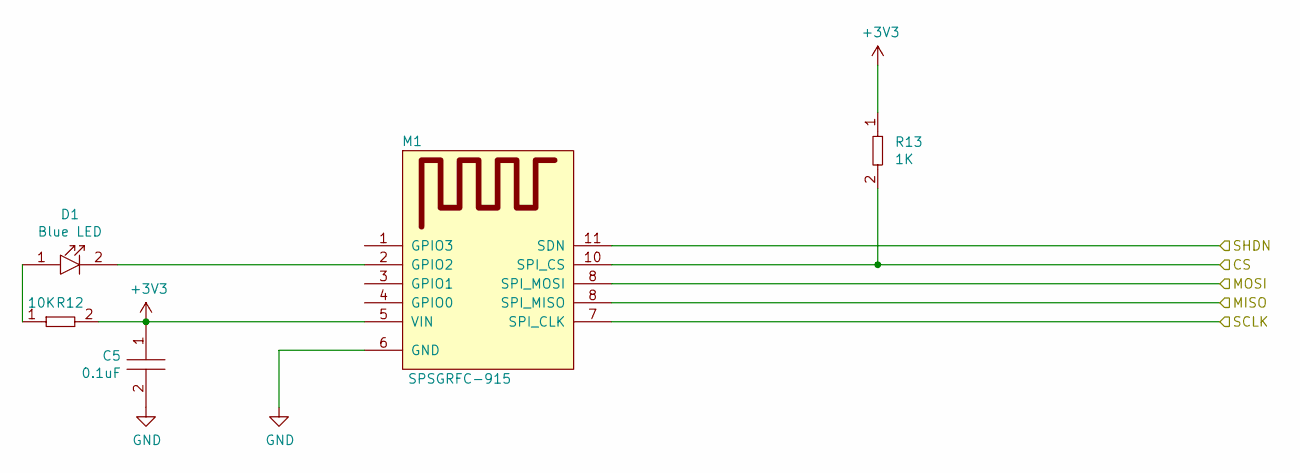
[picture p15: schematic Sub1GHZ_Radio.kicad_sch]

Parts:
C5: C0402C104K9PACTU; R0402; Tolerance 10%; Voltage 6.3V; MFR# C0402C104K9PACTU
D1: LTST-C194TBKT; LED0603; Tolerance *; Voltage 3.3V; MFR# LTST-C194TBKT
M1: SPSGRFC-915; XCVR_SPSGRF-915; Tolerance *; Voltage 1.8V ~ 3.6V; MFR# SPSGRFC-915
R12: RC0402FR-0710KL; R0402; Tolerance 1%; Voltage *; MFR# RC0402FR-0710KL
R13: RC0402FR-071KL; R0402; Tolerance 1%; Voltage *; MFR# RC0402FR-071KL

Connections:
+3V3: C5.1, M1.5 (VIN), R12.2, R13.1; also elsewhere on the board
/915MHZ Radio/Modem/CS: M1.10 (SPI_CS), R13.2; also elsewhere on the board
/915MHZ Radio/Modem/MISO: M1.8 (SPI_MISO); also elsewhere on the board
/915MHZ Radio/Modem/SCLK: M1.7 (SPI_CLK); also elsewhere on the board
/915MHZ Radio/Modem/SHDN: M1.11 (SDN); also elsewhere on the board
GND: C5.2, M1.6 (GND); also elsewhere on the board
unnamed: D1.1, R12.1
unnamed: D1.2, M1.2 (GPIO2)

Board: 2 copper layers, 30 parts (0 on the bottom side), 38 nets, no tracks yet.

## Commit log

2020-06-30 BBG Cape
    Started KiCAD project for BBG cape version. Two RS485 ports using same transceiver as Vine directly wired to BBG serial ports. SPI to UART bridge for radios to follow.
    [Beaglebone_Interface.sch, RS485_Interface.sch, SPI_UART_Bridge.sch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]
2020-07-02 Added UAR Bridge
    Started SPI to UART bridge schematic, still researching part
    [Beaglebone_Interface.sch, RS485_Interface.sch, SPI_UART_Bridge.sch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]
2020-07-07 SPI UART Bridge
    Fleshed out schematic for SPI UART bridge chip, realized we may not need it, now going to fork project and develop two versions in this same repository.
    [Beaglebone_Interface.sch, SPI_UART_Bridge.sch, Vine_Ivy_BRD_Margin.dxf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]
2020-07-07 RPi4 Version and Cape Fork
    Forked the Beaglebone Green Cape version of madre, there are now two variants, one with the SPI to 4 UART bridge and one without that will talk to all Radios/Modems via SPI directly using spare IO pi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
    RPi4 hat version created from a past project, performed all the basic modifications to the schematic to creat the pi version of madre, this one is the most developed version at the moment.
    [Beaglebone_Interface.sch, I2C_MUX.sch, LED_Indication.sch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]
2020-07-08 Datasheets and BBG version
    Finished initial schematic for BBG Gateway version and added datasheets for ST sub 1GHZ RF hardware.
    [Beaglebone_Interface.sch, RS485_Interface.sch, Sub1GHZ_Radio.sch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]
2020-07-08 RPi version PSU
    updated POE circuit with fixed footprint for rectifier diodes.
    [LED_RTC.sch, POE_Power.sch, agricoltura-madre-rpi4-hat.kicad_pcb]
2020-08-18 Board Work
    Board shape added working on cut outs
    [Beaglebone_Interface.sch, agricoltura-madre-cape.kicad_pcb]
2024-03-26 KiCAD 8
    Projected updated to KiCAD 8
    [Beaglebone_Interface.kicad_sch, LED_RTC.kicad_sch, POE_Power.kicad_sch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]

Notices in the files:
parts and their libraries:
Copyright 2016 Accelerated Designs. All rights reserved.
